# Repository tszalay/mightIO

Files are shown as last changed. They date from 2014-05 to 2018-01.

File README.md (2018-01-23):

mightIO
=======

### What

The mightIO is an analog IO board capable of inputting and outputting voltages from -10V to +10V off of a +5V power supply, across four channels, without any external components.

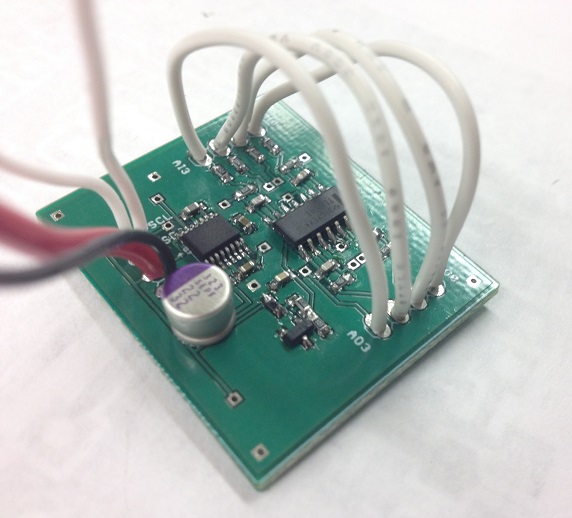
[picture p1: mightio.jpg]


### Why

The mightIO aims to solve the problem "I want to easily read or write analog voltages, in a wide range, decently fast, cheap, and with pretty good accuracy".

Every time I tell my fellow scientists about the Arduino, the first question they ask is "does it have analog outputs?" and I have a tough time explaining why the Arduino can't do it, but also why there aren't any straightforward shields that can do it.

There are shields for all sorts of crazy things, but it seems that analog output shields fall into two categories, either buffered audio output or voltage-limited DAC (eg. less than 0-5V). It's certainly possible to rig up split-rail power supplies and an opamp circuit, but that gets bulky and complicated quickly. 

My philosophy for using Arduino to save time is to "go from working to working", in other words, to be able to make incremental changes keeping everything functional, and this board embodies that much better than having to build I2C DAC + opamp combos from scratch every time.

### How

The +10V and -10V rails are generated using a MAX864 capacitive doubler/inverter chip, running at 180 kHz. The ADC is a MAX11612 and the DAC is a MCP4728, both 12-bit 4-channel I2C chips with range 0V-4.096V. The voltage scaling is performed using two quad TL064 low-power op-amps. The only connections to the Arduino board are +5V, GND, SDA, and SCL. In addition to the 4 inputs and 4 outputs, there is a +10V/GND/-10V breakout.

### Specs

All relevant numbers below are based on actual measurements.
* Footprint: 1.5 in x 1.25 in
* Est. materials cost: $8.90
* Voltage range: 2x Vin, minus about 0.6V droop
* Channels: 4 in, 4 out
* Noise: 40 mV pk-pk, <10 mV RMS (<0.1% noise)
* Resolution: 9 bits raw, 11 bits software median-filtered (<0.1% error)
* Power consumption: 20 mA (no load)
* Maximum effective output load: ~50 mA (3V droop)
* Output impedance: 50 ohms (<1.0V droop @ 1k load)
* Max # of devices: Up to 4 (but I2C addresses need to be reprogrammed) 

### Pricing

The BOM can be found in the repository under "Hardware" - unit cost is estimated at around $8.90 for a run of 1000, of which the ADC, DAC, and doubler each make up about 20%, respectively. This could probably be reduced by about 10% through careful tweaking of the part sourcing/values. Features could also be reduced (fewer channels, removing ADC), but I think the cost overhead is low enough that anyone wanting just an ADC or just a DAC would still buy the board.

I've heard that the retail markup is around 2x, so say the board sells for around $15-$20 - that's cheaper than or comparable to pretty much any other ADC -or- DAC solution out there, with the exception of the much more limited MCP4725 breakout.

### Market

The market for this is anyone that is using Arduinos to interface with a wide range of external devices/sensors/etc that require larger voltage inputs or outputs to function. The key is that it should be priced competitively enough that anyone looking for either a DAC or ADC would consider the board as the simplest and cheapest option.

### Software

The library isn't finished, but the basic parts are all there, just needs some other handy functions and examples. Other features I plan to add are getting the ADC set up in differential input mode to try low-noise measurements and a median-filtered analogRead.

### Who

[Tamas Szalay](http://tamas-szalay.squarespace.com/), full-time Applied Physics grad student and part-time hacker, Arduino afficionado

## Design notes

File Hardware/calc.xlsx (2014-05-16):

Op-amp supply (uA) | 200
Large feedback (kOhm) | 100
Switching frequency (kHz) | 185
Switching capacitance (uF) | 2.2
Target filter freq. (kHz) | 40
Small feedback (kOhm) | 20
Feedback leakage (uA) | 116.6666667
Total current draw (mA) | 2.53
Source impedance (ohm) | 27.45700246
Voltage ripple (mV) | 3.1
Voltage droop (mV) | 69.55773956
Small capacitor (pF) | 39.78873577
Large capacitor (pF) | 198.9436789

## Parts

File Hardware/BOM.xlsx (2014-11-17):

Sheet: 0.1% accurate
Part | Qty | Digikey # | Unit Cost (10) | Unit Cost (1000) | Cost %
47pF | 4 | 1276-1037-1-ND | $0.03 | $0.01 | 0.3%
220pF | 4 | 1276-2237-1-ND | $0.03 | $0.01 | 0.3%
0.1uF | 5 | 399-1096-1-ND | $0.02 | $0.01 | 0.3%
2.2uF | 4 | 587-1253-1-ND | $0.09 | $0.02 | 1.1%
22uF | 1 | P16405CT-ND | $0.99 | $0.59 | 6.6%
1k | 1 | P1.0KYCT-ND | $0.83 | $0.14 | 1.6%
2k | 1 | P2.0KYCT-ND | $0.62 | $0.11 | 1.2%
3.3k | 3 | 311-3.3KGRCT-ND | $0.01 | $0.00204 | 0.1%
5.1k | 1 | P10KDBCT-ND | $0.62 | $0.08 | 0.9%
10k | 1 | P10KDBCT-ND | $0.62 | $0.08 | 0.9%
20k | 4 | P20KDBCT-ND | $0.62 | $0.04 | 1.9%
22k | 4 | P22KDBCT-ND | $0.62 | $0.04 | 1.9%
100k | 8 | P100KDBCT-ND | $0.43 | $0.04 | 3.9%
LM4040 | 1 | LM4040AIM3-2.5/NOPBCT-ND | $1.76 | $0.82 | 9.2%
MAX11612 | 1 | MAX11612EUA+-ND | $1.67 | $1.66 | 18.6%
MAX864 | 1 | MAX864EEE+-ND | $3.76 | $1.68 | 18.9%
MCP4728 | 1 | MCP4728A0-E/UN-ND | $1.89 | $1.44 | 16.2%
TL064 | 2 | 296-14992-1-ND | $0.50 | $0.21 | 4.8%
Board (est.) | 1 |  | $1.00 | $1.00 | 11.2%
Total cost |  |  | $23.90 | $8.89

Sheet: 1% accurate
Part | Qty | Digikey # | Unit Cost (10) | Unit Cost (1000) | Cost %
47pF | 4 | 1276-1037-1-ND | $0.03 | $0.01 | 0.3%
220pF | 4 | 1276-2237-1-ND | $0.03 | $0.01 | 0.4%
0.1uF | 5 | 399-1096-1-ND | $0.02 | $0.01 | 0.4%
2.2uF | 4 | 587-1253-1-ND | $0.09 | $0.02 | 1.3%
22uF | 1 | P16405CT-ND | $0.99 | $0.59 | 7.8%
1k | 1 | RHM1.00KCFCT-ND | $0.10 | $0.004 | 0.1%
2k | 1 | RHM2.00KCFCT-ND | $0.10 | $0.004 | 0.1%
3.3k | 3 | RHM3.30KCFCT-ND | $0.10 | $0.004 | 0.2%
5.1k | 1 | RHM5.10KCFCT-ND | $0.10 | $0.004 | 0.1%
10k | 1 | RHM10.0KCFCT-ND | $0.10 | $0.004 | 0.1%
20k | 4 | RHM20.0KCFCT-ND | $0.10 | $0.004 | 0.2%
22k | 4 | RHM22.0KCFCT-ND | $0.10 | $0.004 | 0.2%
100k | 8 | RHM100KCFCT-ND | $0.10 | $0.004 | 0.4%
LM4040 | 1 | LM4040DIX3-2.5+TCT-ND | $0.73 | $0.44 | 5.9%
MAX11612 | 1 | MAX11612EUA+-ND | $1.67 | $1.66 | 22.1%
MAX864 | 1 | MAX864EEE+-ND | $3.76 | $1.68 | 22.4%
MCP4728 | 1 | MCP4728A0-E/UN-ND | $1.89 | $1.44 | 19.2%
TL064 | 2 | 296-14992-1-ND | $0.50 | $0.21 | 5.6%
Board (est.) | 1 |  | $1.00 | $1.00 | 13.3%
Total cost |  |  | $14.05 | $7.51

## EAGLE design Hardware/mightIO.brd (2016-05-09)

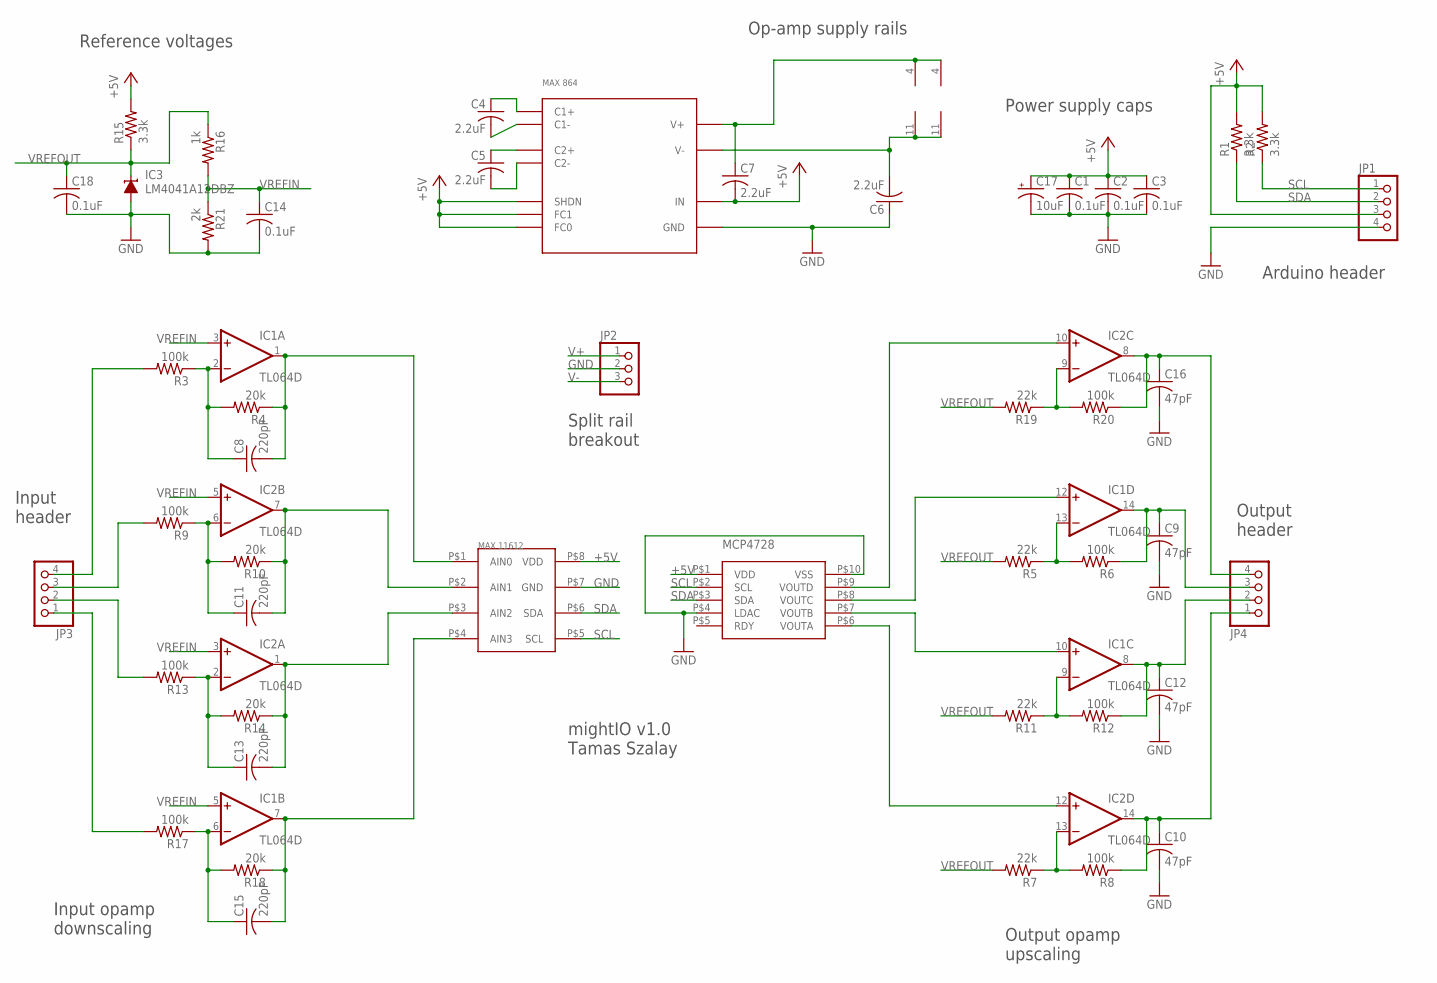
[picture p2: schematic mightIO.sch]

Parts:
C1, C2, C3, C14, C18: 0.1uF; C0603
C4, C5, C6, C7: 2.2uF; C0603
C8, C11, C13, C15: 220pF; C0603
C9, C10, C12, C16: 47pF; C0603
C17: 10uF; E2,5-6
IC1, IC2: TL064D; SO14
IC3: LM4041A12DBZ; DBZ_R-PDSO-G3
JP1, JP3, JP4: PINHD-1X4; 1X04
JP2: PINHD-1X3; 1X03
R1, R2, R15: 3.3k; R0603
R3, R6, R8, R9, R12, R13, R17, R20: 100k; R0603
R4, R10, R14, R18: 20k; R0603
R5, R7, R11, R19: 22k; R0603
R16: 1k; R0603
R21: 2k; R0603
U1: MAX11612
U$1: MAX864
U$2: MCP4728

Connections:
+5V: C1.1, C2.1, C3.1, C7.2, C17.+, JP1.3, R1.2, R2.2, R15.2, U1.P$8 (VDD), U$1.P$6 (SHDN), U$1.P$7 (FC1), U$1.P$8 (FC0), U$1.P$12 (IN), U$2.P$1 (VDD)
AI0: JP3.4, R3.2
AI1: JP3.3, R9.2
AI2: JP3.2, R13.2
AI3: JP3.1, R17.2
AOA: C10.1, IC2.14 (OUT), JP4.1, R8.1
AOB: C12.1, IC1.8 (OUT), JP4.2, R12.1
AOC: C9.1, IC1.14 (OUT), JP4.3, R6.1
AOD: C16.1, IC2.8 (OUT), JP4.4, R20.1
GND: C1.2, C2.2, C3.2, C6.1, C9.2, C10.2, C12.2, C14.2, C16.2, C17.-, C18.2, IC3.2 (A), JP1.4, JP2.2, R21.2, U1.P$7 (GND), U$1.P$3 (GND), U$1.P$11 (GND), U$2.P$4 (LDAC), U$2.P$10 (VSS)
unnamed: IC2.10 (+IN), U$2.P$9 (VOUTD)
unnamed: IC2.9 (-IN), R19.1, R20.2
unnamed: IC1.10 (+IN), U$2.P$7 (VOUTB)
unnamed: IC1.13 (-IN), R5.1, R6.2
unnamed: IC1.9 (-IN), R11.1, R12.2
unnamed: IC2.13 (-IN), R7.1, R8.2
unnamed: C4.1, U$1.P$16 (C1+)
unnamed: C4.2, U$1.P$1 (C1-)
unnamed: C5.1, U$1.P$2 (C2+)
unnamed: C5.2, U$1.P$4 (C2-)
unnamed: C8.1, IC1.2 (-IN), R3.1, R4.2
unnamed: C13.2, IC2.1 (OUT), R14.1, U1.P$3 (AIN2)
unnamed: C8.2, IC1.1 (OUT), R4.1, U1.P$1 (AIN0)
unnamed: C11.1, IC2.6 (-IN), R9.1, R10.2
unnamed: C11.2, IC2.7 (OUT), R10.1, U1.P$2 (AIN1)
unnamed: C15.2, IC1.7 (OUT), R18.1, U1.P$4 (AIN3)
unnamed: C13.1, IC2.2 (-IN), R13.1, R14.2
unnamed: IC2.12 (+IN), U$2.P$6 (VOUTA)
unnamed: C15.1, IC1.6 (-IN), R17.1, R18.2
unnamed: IC1.12 (+IN), U$2.P$8 (VOUTC)
SCL: JP1.1, R2.1, U1.P$5 (SCL), U$2.P$2 (SCL)
SDA: JP1.2, R1.1, U1.P$6 (SDA), U$2.P$3 (SDA)
V+: C7.1, IC1.4 (V+), IC2.4 (V+), JP2.1, U$1.P$15 (V+)
V-: C6.2, IC1.11 (V-), IC2.11 (V-), JP2.3, U$1.P$5 (V-)
VREFIN: C14.1, IC1.3 (+IN), IC1.5 (+IN), IC2.3 (+IN), IC2.5 (+IN), R16.2, R21.1
VREFOUT: C18.1, IC3.1 (C), R5.2, R7.2, R11.2, R15.1, R16.1, R19.2

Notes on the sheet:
Output header
Input header
Reference voltages
Input opamp downscaling
Output opamp upscaling
Arduino header
Power supply caps
Op-amp supply rails
mightIO v1.0 Tamas Szalay
Split rail breakout

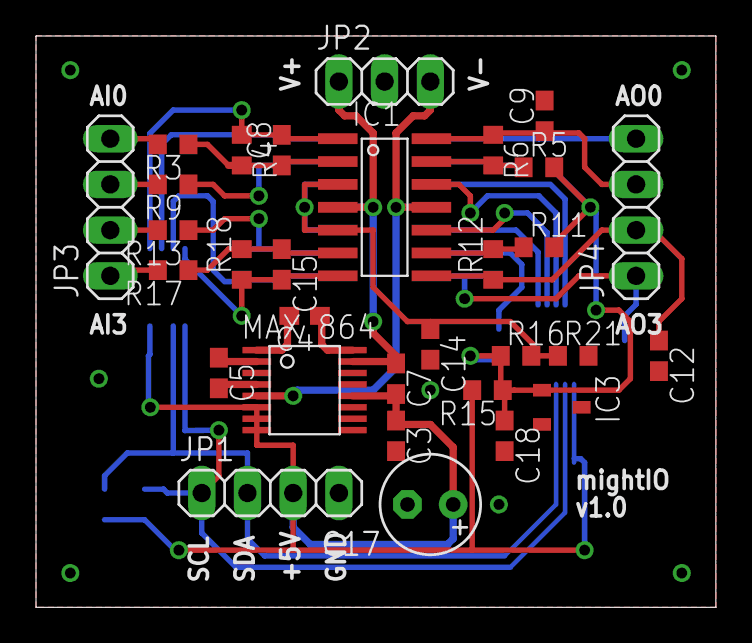
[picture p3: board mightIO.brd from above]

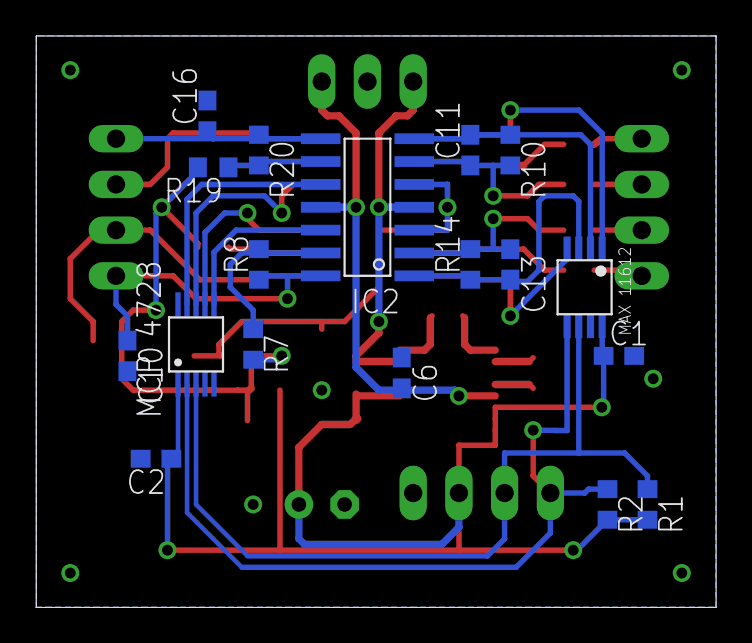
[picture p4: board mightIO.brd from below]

Board: 2 copper layers, 37.8 x 31.7 mm, 49 parts (18 on the bottom side), 36 nets.

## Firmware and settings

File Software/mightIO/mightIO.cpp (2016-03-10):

/*
  mightIO.cpp - Arduino library for mightIO boosted analog IO board
*/

#include "mightIO.h"

#define VAL_SORT(a,b) { if ((a)>(b)) VAL_SWAP((a),(b)); }
#define VAL_SWAP(a,b) { int16_t temp=(a);(a)=(b);(b)=temp; }

int16_t opt_med5(int16_t * p)
{
    VAL_SORT(p[0],p[1]) ; VAL_SORT(p[3],p[4]) ; VAL_SORT(p[0],p[3]) ;
    VAL_SORT(p[1],p[4]) ; VAL_SORT(p[1],p[2]) ; VAL_SORT(p[2],p[3]) ;
    VAL_SORT(p[1],p[2]) ; return(p[2]) ;
}

int16_t opt_med7(int16_t * p)
{
    VAL_SORT(p[0], p[5]) ; VAL_SORT(p[0], p[3]) ; VAL_SORT(p[1], p[6]) ;
    VAL_SORT(p[2], p[4]) ; VAL_SORT(p[0], p[1]) ; VAL_SORT(p[3], p[5]) ;
    VAL_SORT(p[2], p[6]) ; VAL_SORT(p[2], p[3]) ; VAL_SORT(p[3], p[6]) ;
    VAL_SORT(p[4], p[5]) ; VAL_SORT(p[1], p[4]) ; VAL_SORT(p[1], p[3]) ;
    VAL_SORT(p[3], p[4]) ; return (p[3]) ;
}

// borrowed from the fantastic FastLED/lib8tion.h library (score MIT license!)
// note that this function operates only on unsigned ints!
uint16_t scale16by8( int16_t i, uint8_t scale )
{
    uint16_t result = 0;
    asm volatile(
         // result.A = HighByte(i.A x j )
         "  mul %A[i], %[scale]                 \n\t"
         "  mov %A[result], r1                  \n\t"
         //"  clr %B[result]                      \n\t"

         // result.A-B += i.B x j
         "  mul %B[i], %[scale]                 \n\t"
         "  add %A[result], r0                  \n\t"
         "  adc %B[result], r1                  \n\t"

         // cleanup r1
         "  clr __zero_reg__                    \n\t"

         : [result] "+r" (result)
         : [i] "r" (i), [scale] "r" (scale)
         : "r0", "r1"
         );
    return result;
}

// Initialize class and device addresses from IDs
mightIO::mightIO(uint8_t dacID, uint8_t adcID) : adcLastConfig(0)
{
  this->dacAddr = (DAC_BASE_ADDR | dacID);
  this->adcAddr = (ADC_BASE_ADDR | adcID);
}

// Or without addresses, default to 0 for both
mightIO::mightIO() : dacAddr(DAC_BASE_ADDR), adcAddr(ADC_BASE_ADDR)
{}


// Begin I2C and configure chips
void mightIO::begin()
{
  Wire.begin();
  this->dacSetVref();
  this->dacSetGain();
  this->adcSetup();
  this->defaultCalib();
}

// performance not super important here
void mightIO::defaultCalib()
{
  // DAC voltage divider
  uint8_t R1 = 22;
  uint8_t R2 = 100;
  
  // start it off at the Vref value, 2.5V
  uint32_t dac_off = 2500;
  // then do our handy calculation for offset (in mV)
  dac_off = (dac_off*R2)/R1;
  // and the scaling, *256 for the eventual division by 256 in scaling
  this->dac_scale = (R1*256)/(R1+R2);
  
  for (int i=0; i<4; i++)
    this->dac_offset[i] = dac_off;
  
  // now for the ADC
  R1 = 20;
  
  this->adc_scale = R2/R1;
  
  // vref is scaled down from 2.5V by resistors
  // so replace this number with that vref, depending
  uint16_t adc_off = 1667;
  // scale it by the resistors, assuming they divide nicely
  adc_off = (1+R2/R1)*adc_off;
  for (int i=0; i<4; i++)
    this->adc_offset[i] = adc_off;
}

// Write all (four) values to the DAC
// Values should be specified in mV, roughly -10000 to 10000
void mightIO::analogWrite(int16_t vout[])
{
  Wire.beginTransmission(this->dacAddr);
  // leading the first byte with 0b00 implicitly starts a 'fast write'
  for (uint8_t i=0; i<4; i++)
  {
    uint16_t val = 4095&scale16by8(vout[3-i]+this->dac_offset[3-i],this->dac_scale);
	// this is implicitly setting PD1,PD0 to 0 in upper bytes
	// which means normal operation
    Wire.write(highByte(val));
    Wire.write(lowByte(val));
  }
  Wire.endTransmission();
}

// Write a single value to the specified DAC channel (0...3)
void mightIO::analogWrite(uint8_t ch, int16_t vout)
{
  Wire.beginTransmission(this->dacAddr);
  
  uint16_t val = 4095&scale16by8(vout+this->dac_offset[3-ch],this->dac_scale);
  
  // reverse channel
  ch = 3-ch;
  // create a single-write command
  Wire.write(DAC_MULTIWRITE | (ch << 1));
  // and write the data, with Vref, PD, and gain set appropriately
  Wire.write(0b10010000 | highByte(val));
  Wire.write(lowByte(val));

  Wire.endTransmission();
}


// Read a single ADC channel
int16_t mightIO::analogRead(uint8_t ch)
{
  this->adcConfig(ch, true);
  
  Wire.requestFrom(this->adcAddr, (uint8_t)2);
  int16_t vin = (Wire.read() & 0xF) << 8;
  vin = vin | Wire.read();
  return this->adc_offset[ch] - this->adc_scale*vin;
}

// Read ADC inputs in order, as many as specified
void mightIO::analogRead(int16_t vin[], uint8_t nchan)
{
  // set to scan to nchan-1
  this->adcConfig(nchan-1, false);
  // and read all of the bytes
  Wire.requestFrom((int)this->adcAddr,2*nchan);
  for (uint8_t i=0; i<nchan; i++)
  {
	int16_t v = (Wire.read() & 0xF) << 8;
	v = v | Wire.read();
	vin[i] = this->adc_offset[i] - this->adc_scale*v;
  }
}
// or all of them, call with 4
void mightIO::analogRead(int16_t vin[])
{
  this->analogRead(vin,4);
}

// and some filtered ones
int16_t mightIO::analogReadFilter(uint8_t ch)
{
	int16_t vals[7];
	
	for (int i=0; i<7; i++)
		vals[i] = analogRead(ch);
		
	return opt_med7(vals);
}

//calibration functions
void mightIO::adjustOffsetADC(int offset[])
{
  for (int i=0; i<4; i++)
    this->adc_offset[i] += offset[i];
}

void mightIO::adjustOffsetDAC(int offset[])
{
  for (int i=0; i<4; i++)
    this->dac_offset[i] += offset[i];
}

// Private function to set config byte, does nothing if already set
inline void mightIO::adcConfig(uint8_t ch, bool scanone)
{
  uint8_t cfg = ADC_CFGSINGLE | (ch << 1) | (scanone?ADC_CFGSCANONE:0);
  // if same as previous, don't need to write
  if (cfg == this->adcLastConfig)
    return;
  
  // else write and save
  Wire.beginTransmission(this->adcAddr);
  Wire.write(cfg);
  Wire.endTransmission();
  
  this->adcLastConfig = cfg;
}

// Private function - write ADC setup bytes
void mightIO::adcSetup()
{
  Wire.beginTransmission(this->adcAddr);
  Wire.write(ADC_SETUPBYTE | ADC_SETSEL);
  Wire.endTransmission();
}

// Private function - set to use internal 2.048V reference
void mightIO::dacSetVref()
{
  Wire.beginTransmission(this->dacAddr);
  Wire.write(DAC_VREFWRITE | 0b1111);
  Wire.endTransmission();
}

// Private function - sets DAC gain to 2 (to go 0...4095)
void mightIO::dacSetGain()
{
  Wire.beginTransmission(this->dacAddr);
  Wire.write(DAC_GAINWRITE | 0b1111);
  //Wire.write(DAC_GAINWRITE | 0b0000); would set gain to 1
  Wire.endTransmission();
}

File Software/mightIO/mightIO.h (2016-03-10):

/*
Arduino library for mightIO 10V ADC/DAC board
*/

#ifndef mightIO_h
#define mightIO_h

#include "Arduino.h"
#include <Wire.h>

#define DAC_BASE_ADDR 	0x60

#define DAC_MULTIWRITE 	0B01000000
#define DAC_SINGLEWRITE 0B01011000
#define DAC_SEQWRITE 	0B01010000
#define DAC_VREFWRITE 	0B10000000
#define DAC_PWRDNWRITE 	0B10100000
#define DAC_GAINWRITE 	0B11000000

#define ADC_BASE_ADDR	0B0110100
#define ADC_SETUPBYTE   0B10000000
#define ADC_SETBIPOLAR	0B0000100
#define ADC_SETSEL		0B1010000
#define ADC_CFGSINGLE	0B0000001
#define ADC_CFGSCANONE	0B1100000


class mightIO
{
  public:
	mightIO();
    mightIO(uint8_t dacID, uint8_t adcID);
	
    void     	begin();
        
	// DAC output functions
	void		analogWrite(uint8_t ch, int16_t vout);  	// single channel
	void  		analogWrite(int16_t vout[]); 				// all channels
	
	// ADC input functions
	int16_t 	analogRead(uint8_t ch); 					// single channel
	void 		analogRead(int16_t vin[]); 					// all channels
	void 		analogRead(int16_t vin[], uint8_t nchan); 	// first n channels
	int16_t 	analogReadFilter(uint8_t ch); 				// read single channel, median-filtered
	
    // A serial output-using function
    void     	print();
    
    // calibration functions
    // these offset the default values by a few ticks for 'tweaking' the calib
    void        adjustOffsetADC(int offset[]);
    void        adjustOffsetDAC(int offset[]);

  private:  
    uint8_t		dacAddr;
	uint8_t		adcAddr;
	
	uint8_t		adcLastConfig; 							// the most recent config byte sent
    
    int16_t     adc_offset[4];                          // additive component of ADC scaling
    int16_t     dac_offset[4];                          // additive component of ADC scaling
	uint8_t		adc_scale;								// scaling, fixed at startup
	uint8_t		dac_scale;								// scaling, fixed at startup
	
	void		dacSetGain(); 							// set Gain to 2 on all channels
	void		dacSetVref(); 							// set Vref to internal 2.048V
	
	void		adcSetup(); 							// write setup byte
	void		adcConfig(uint8_t ch, bool scanone); 	// write config byte
    
    void        defaultCalib();                         // quick calculation for default calibration values
};
#endif

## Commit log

2014-07-15 Some part value updates
    [mightIO.brd, mightIO.sch]
2014-07-30 Some routing updates, more needed
    [mightIO.brd, mightIO.sch]
2014-09-18 Layout tweaks, added cap
    [mightIO.brd, mightIO.sch]
2014-09-18 Added silkscreen, ready to go
    [mightIO.brd, mightIO.sch]
2014-09-19 Gerber files done
    [mightIO.brd, mightIO_tile.brd]
2014-09-23 Added aluminum polymer to BOM
    [BOM.xlsx]
2014-10-12 Library updates
    [BOM.xlsx]
2014-10-13 Switched output amplifiers to non-inverting
    [mightIO.brd, mightIO.sch]
2014-10-15 Touched up silkscreen, moved caps
    [mightIO.brd, mightIO.sch]
2014-10-15 BOM updates, added 1% calculation
    [BOM.xlsx]
2014-10-15 Something changed?
    [BOM.xlsx]
2014-10-16 Updated tiled board
    [mightIO_tile.brd]
2014-11-17 BOM updates
    [BOM.xlsx]
2014-11-17 Added pdf schematic
2016-03-10 Adding some calibration ability
2016-03-10 Fixed up previous bugs in offsets
    [mightIO.brd, mightIO.sch]
2016-05-09 Annotated schematic and labeled board
    [mightIO.brd, mightIO.sch, mightIO_tile.brd]
